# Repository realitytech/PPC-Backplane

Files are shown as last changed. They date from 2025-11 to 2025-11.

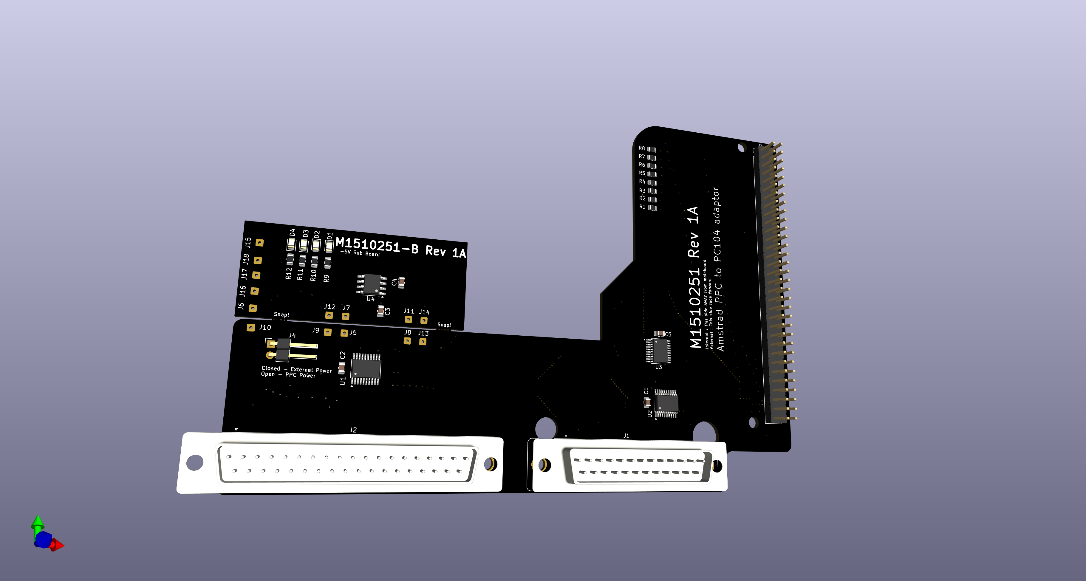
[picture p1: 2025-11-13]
M1510251 - PPC Conn.png

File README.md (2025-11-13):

# PPC-Backplane
Amstrad PPC640 and PPC512 Internal PC104 Backplane

M1510251 - PPC Conn

This adds an internal PC104 compatible slot to the PPC640 and PPC512 in the modem bay.
The board is designed to fit inside the machine soldering on the underside of the main board but can be fitted with through hole sockets and used externally too for testing and development.

This is the inital release version and corrects a few issues with the very first issue. The schematic and PCB need tidying.

NOTE: This version is UNTESTED and has not been built yet. It *should* work as it's an evolution of a design that DOES work. However it's missing changes that the test board has, notably.
Pullups on A8-A16, these seem to be not needed on all units.
Pullups on D0-D7 are optional, both units I have here already have these on the board.

The plan is to move to 74xxx16245 chips to keep to two chips but buffer ALL lines.

Licence/Useage:
Please credit the source. This is a non-commercial project and you may do with it as you wish for PERSONAL USE ONLY
Commercial use is strictly forbidden.

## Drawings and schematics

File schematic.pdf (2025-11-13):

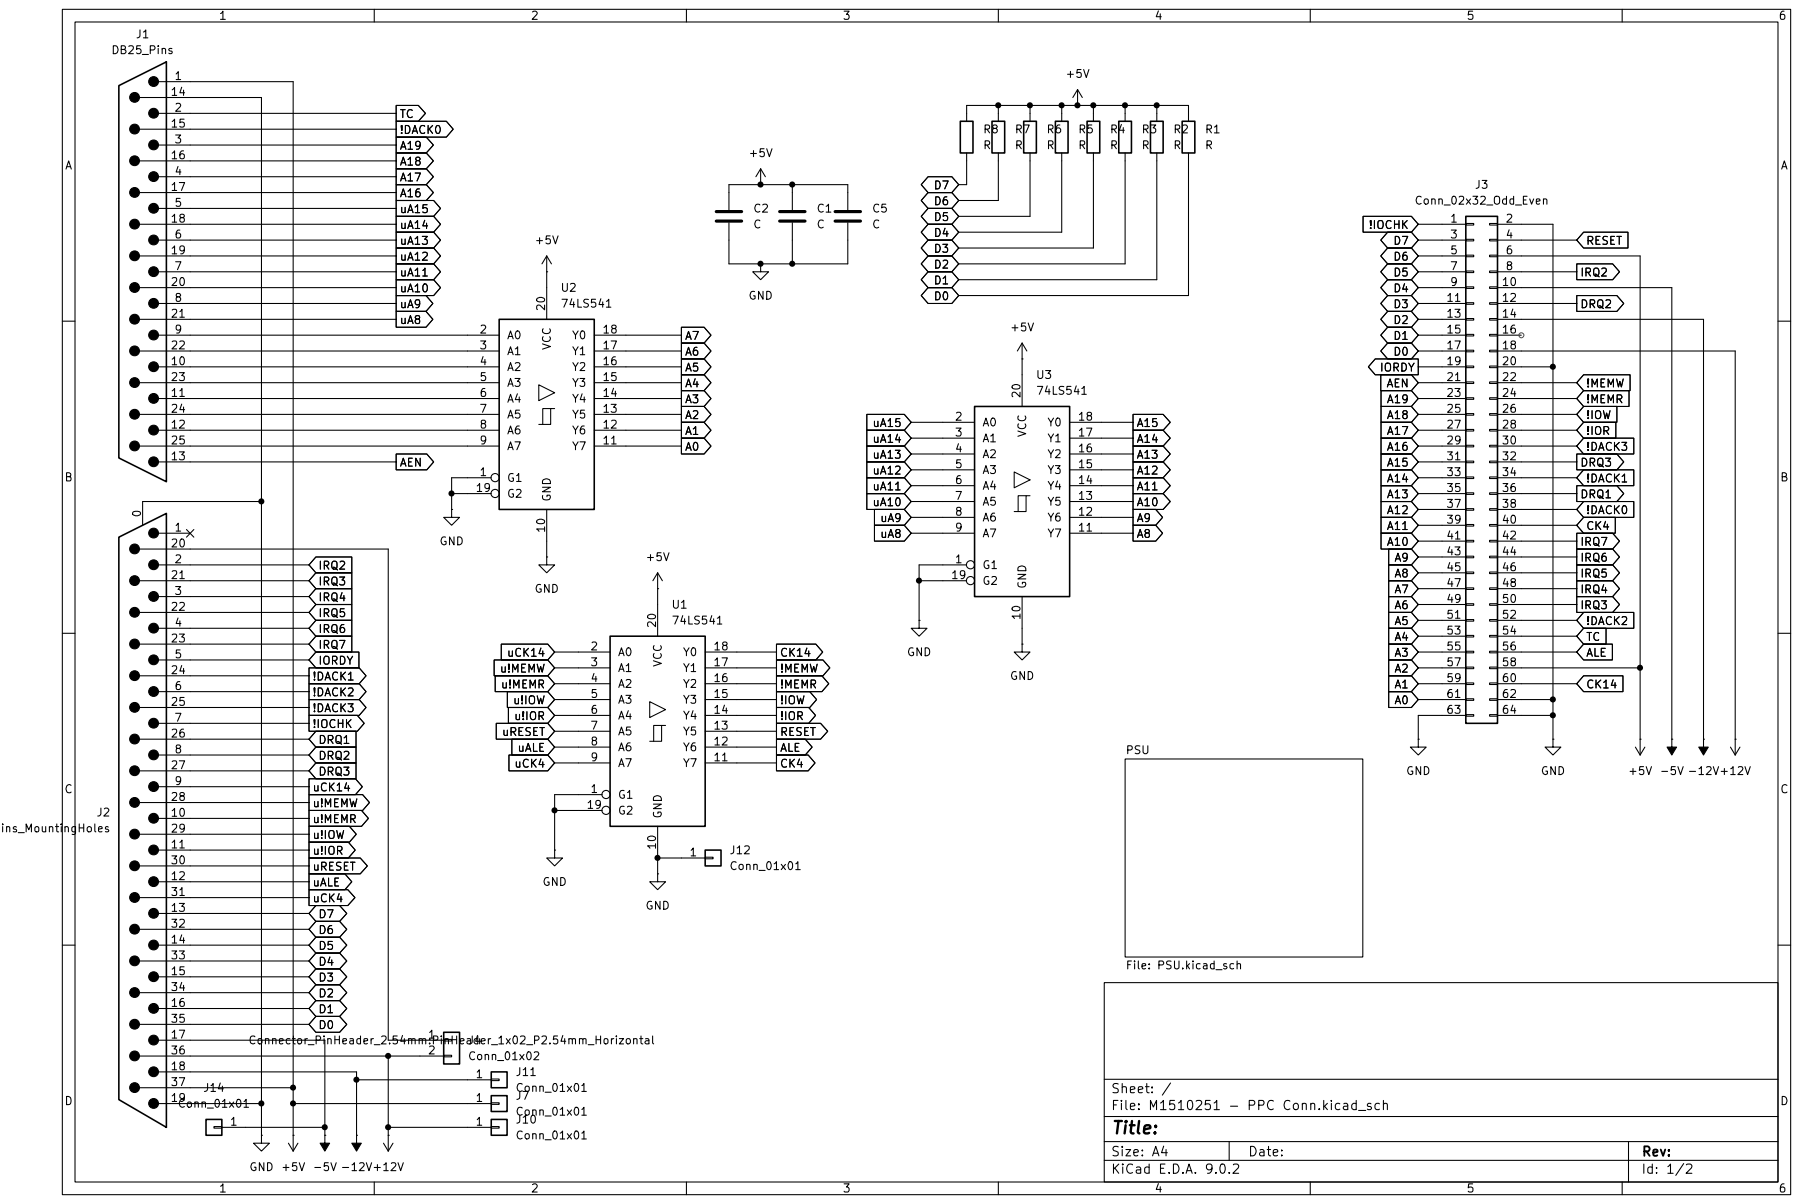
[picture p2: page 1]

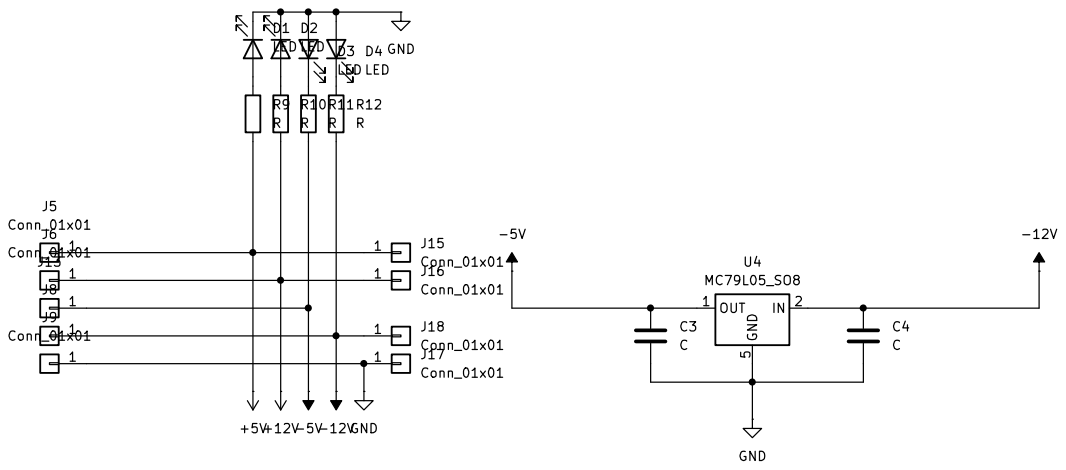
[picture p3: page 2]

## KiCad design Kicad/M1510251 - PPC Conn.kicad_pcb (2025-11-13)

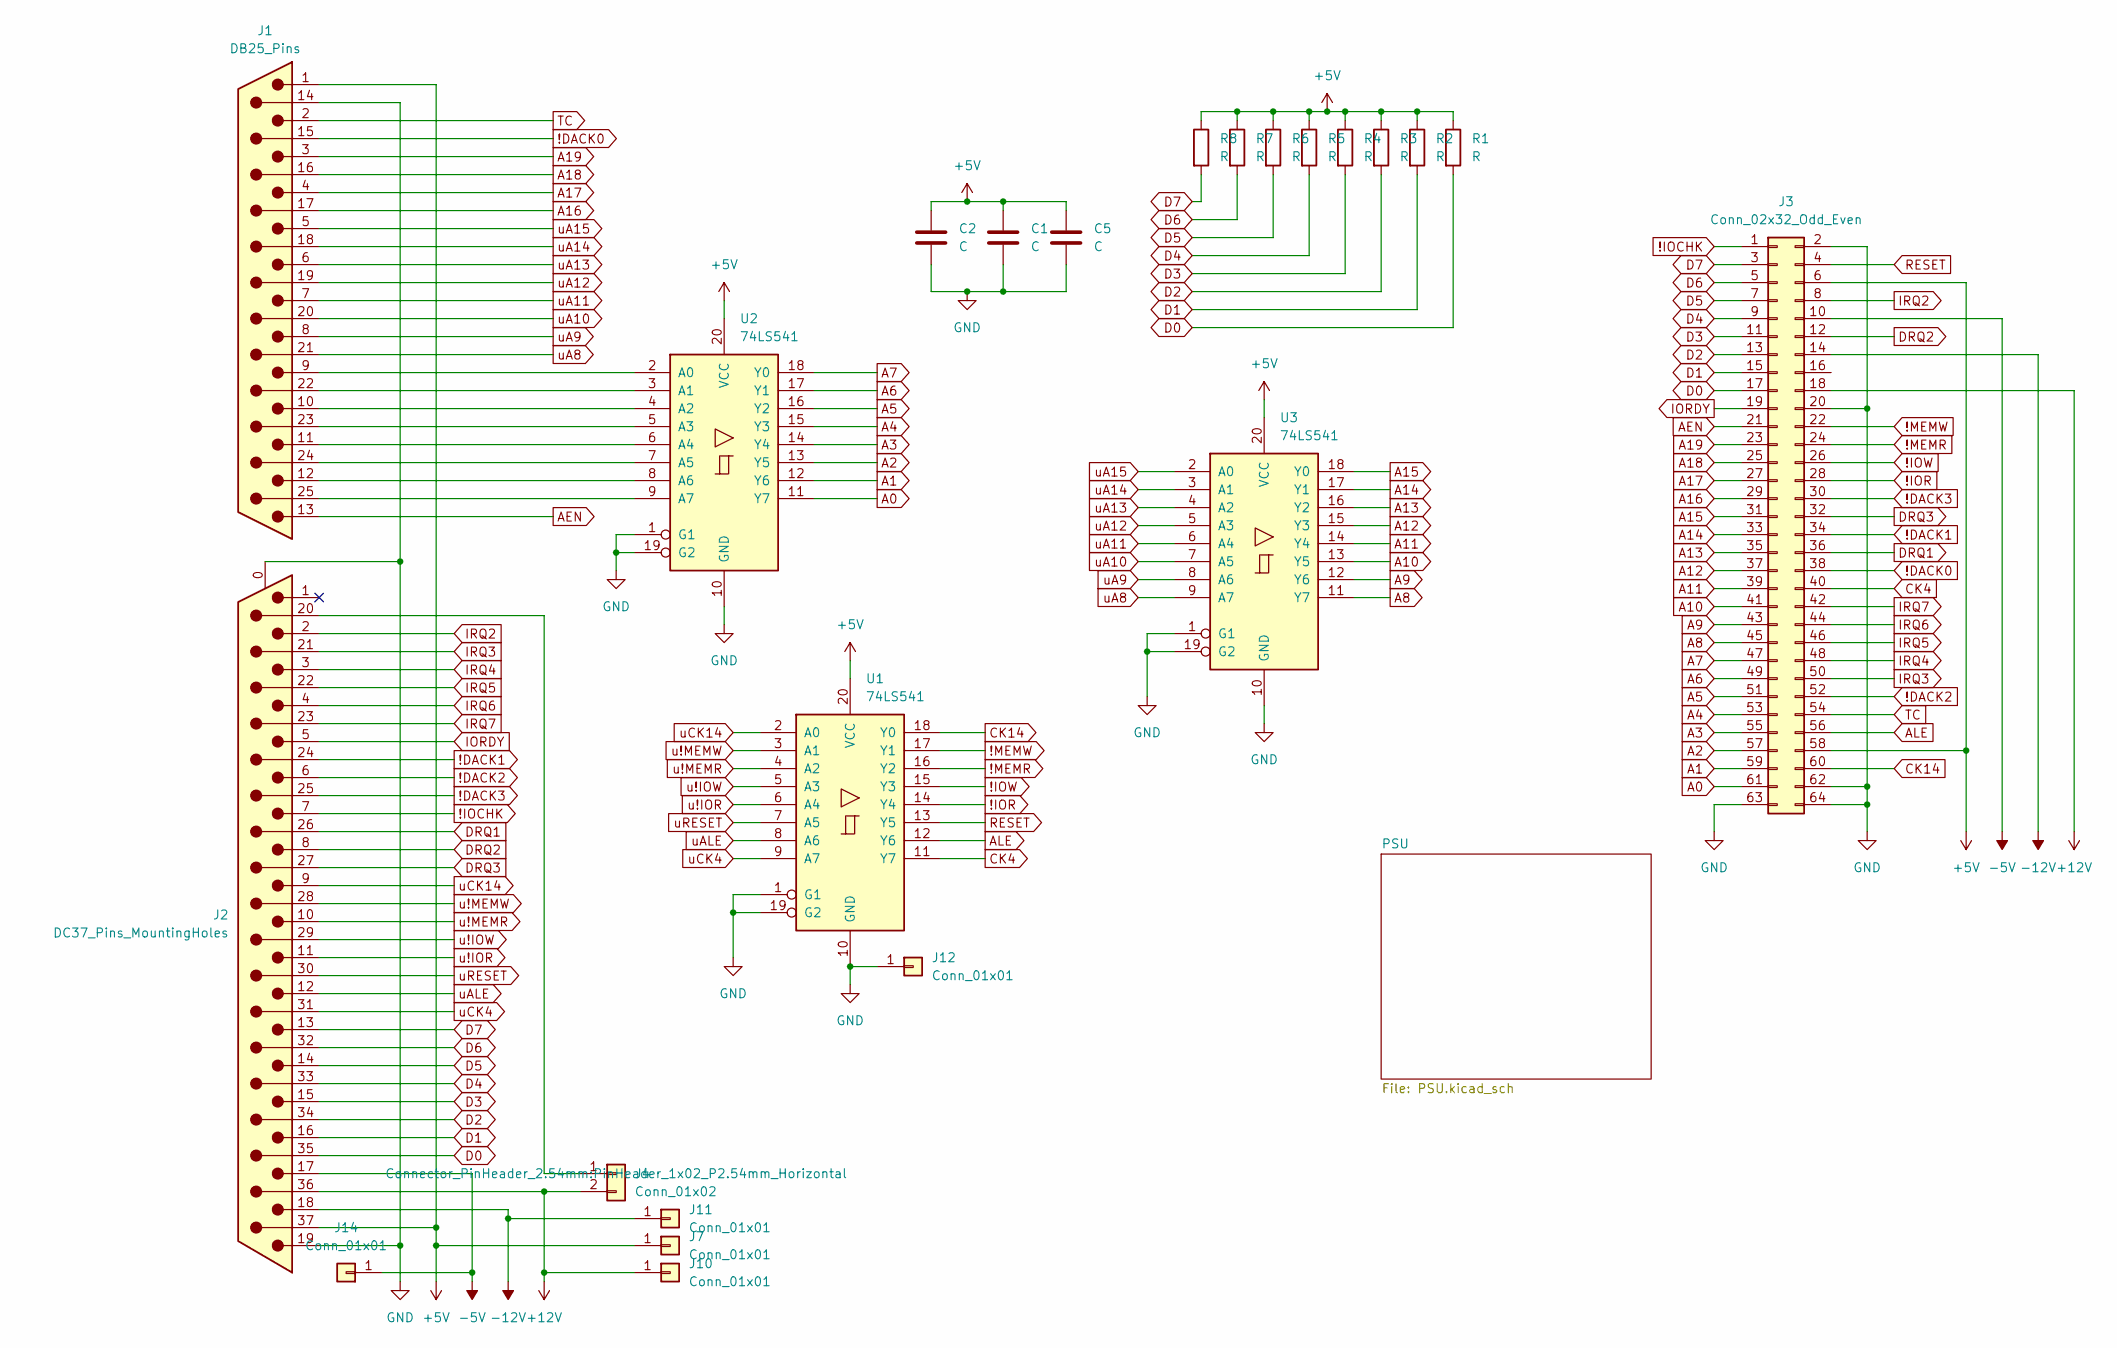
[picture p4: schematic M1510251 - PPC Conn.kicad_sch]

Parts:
C1, C2, C5: C; C_0805_2012Metric
J1: DB25_Pins; DSUB-25_Pins_Vertical_P2.77x2.84mm_MountingHoles
J2: DC37_Pins_MountingHoles; DSUB-37_Pins_Vertical_P2.77x2.84mm_MountingHoles
J3: Conn_02x32_Odd_Even; PinHeader_2x32_P2.54mm_Vertical
J4: Conn_01x02; PinHeader_1x02_P2.54mm_Horizontal
J7, J10, J11, J12, J14: Conn_01x01; SolderWire-0.15sqmm_1x01_D0.5mm_OD1.5mm
R1, R2, R3, R4, R5, R6, R7, R8: R; R_0805_2012Metric
U1, U2, U3: 74LS541; SSOP-20_4.4x6.5mm_P0.65mm

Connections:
!DACK0: J1.15, J3.38
!DACK1: J2.24, J3.34
!DACK2: J2.6, J3.52
!DACK3: J2.25, J3.30
!IOCHK: J2.7, J3.1
!IOR: J3.28, U1.14 (Y4)
!IOW: J3.26, U1.15 (Y3)
!MEMR: J3.24, U1.16 (Y2)
!MEMW: J3.22, U1.17 (Y1)
+5V: C1.1, C2.1, C5.1, J1.1, J2.37, J3.6, J3.58, J7.1, R1.1, R2.1, R3.1, R4.1, R5.1, R6.1, R7.1, R8.1, U1.20 (VCC), U2.20 (VCC), U3.20 (VCC); also elsewhere on the board
+12V: J2.36, J3.18, J4.2, J10.1; also elsewhere on the board
-5V: J2.17, J3.10, J14.1; also elsewhere on the board
-12V: J2.18, J3.14, J11.1; also elsewhere on the board
A0: J3.61, U2.11 (Y7)
A1: J3.59, U2.12 (Y6)
A2: J3.57, U2.13 (Y5)
A3: J3.55, U2.14 (Y4)
A4: J3.53, U2.15 (Y3)
A5: J3.51, U2.16 (Y2)
A6: J3.49, U2.17 (Y1)
A7: J3.47, U2.18 (Y0)
A8: J3.45, U3.11 (Y7)
A9: J3.43, U3.12 (Y6)
A10: J3.41, U3.13 (Y5)
A11: J3.39, U3.14 (Y4)
A12: J3.37, U3.15 (Y3)
A13: J3.35, U3.16 (Y2)
A14: J3.33, U3.17 (Y1)
A15: J3.31, U3.18 (Y0)
A16: J1.17, J3.29
A17: J1.4, J3.27
A18: J1.16, J3.25
A19: J1.3, J3.23
AEN: J1.13, J3.21
ALE: J3.56, U1.12 (Y6)
CK4: J3.40, U1.11 (Y7)
CK14: J3.60, U1.18 (Y0)
D0: J2.35, J3.17, R1.2
D1: J2.16, J3.15, R2.2
D2: J2.34, J3.13, R3.2
D3: J2.15, J3.11, R4.2
D4: J2.33, J3.9, R5.2
D5: J2.14, J3.7, R6.2
D6: J2.32, J3.5, R7.2
D7: J2.13, J3.3, R8.2
DRQ1: J2.26, J3.36
DRQ2: J2.8, J3.12
DRQ3: J2.27, J3.32
GND: C1.2, C2.2, C5.2, J1.14, J2.0 (PAD), J2.19, J3.2, J3.20, J3.62, J3.63, J3.64, J12.1, U1.1 (G1), U1.10 (GND), U1.19 (G2), U2.1 (G1), U2.10 (GND), U2.19 (G2), U3.1 (G1), U3.10 (GND), U3.19 (G2); also elsewhere on the board
IORDY: J2.5, J3.19
IRQ2: J2.2, J3.8
IRQ3: J2.21, J3.50
IRQ4: J2.3, J3.48
IRQ5: J2.22, J3.46
IRQ6: J2.4, J3.44
IRQ7: J2.23, J3.42
unnamed: J1.22, U2.3 (A1)
unnamed: J1.23, U2.5 (A3)
unnamed: J1.24, U2.7 (A5)
unnamed: J1.25, U2.9 (A7)
unnamed: J2.20, J4.1
unnamed: J1.9, U2.2 (A0)
unnamed: J1.10, U2.4 (A2)
unnamed: J1.11, U2.6 (A4)
unnamed: J1.12, U2.8 (A6)
RESET: J3.4, U1.13 (Y5)
TC: J1.2, J3.54
u!IOR: J2.11, U1.6 (A4)
u!IOW: J2.29, U1.5 (A3)
u!MEMR: J2.10, U1.4 (A2)
u!MEMW: J2.28, U1.3 (A1)
uA8: J1.21, U3.9 (A7)
uA9: J1.8, U3.8 (A6)
uA10: J1.20, U3.7 (A5)
uA11: J1.7, U3.6 (A4)
uA12: J1.19, U3.5 (A3)
uA13: J1.6, U3.4 (A2)
uA14: J1.18, U3.3 (A1)
uA15: J1.5, U3.2 (A0)
uALE: J2.12, U1.8 (A6)
uCK4: J2.31, U1.9 (A7)
uCK14: J2.9, U1.2 (A0)
uRESET: J2.30, U1.7 (A5)

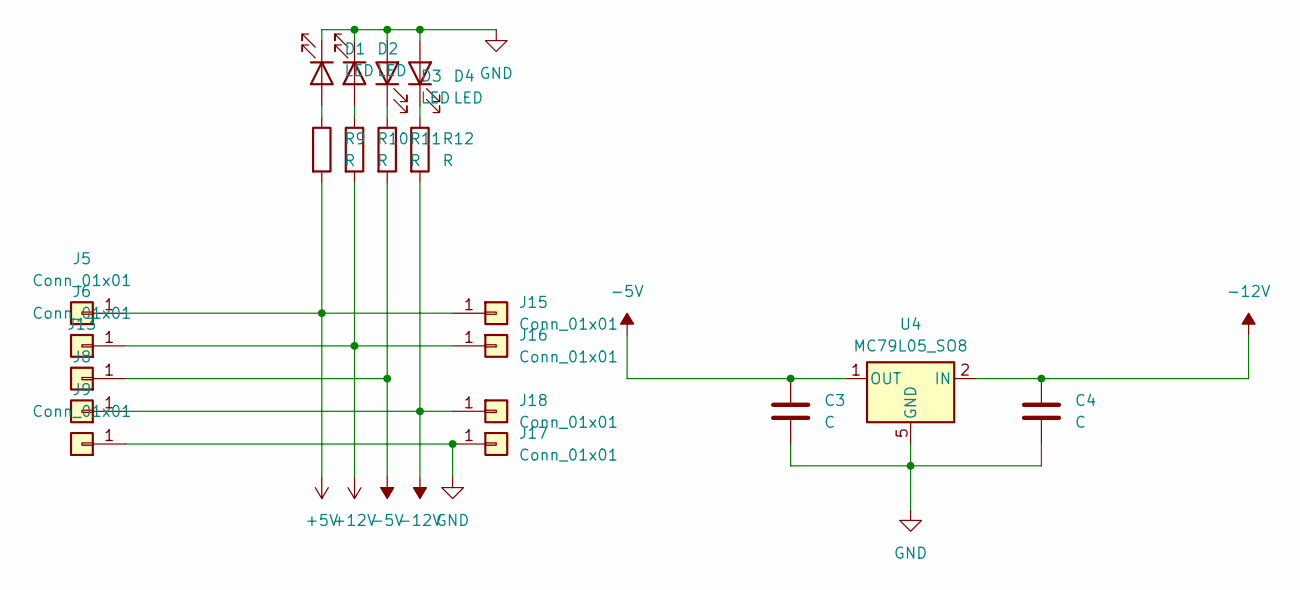
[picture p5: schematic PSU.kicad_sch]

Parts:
C3, C4: C; C_0805_2012Metric
D1, D2, D3, D4: LED; LED_0805_2012Metric
J5, J6, J8, J9, J13, J15, J16, J17, J18: Conn_01x01; SolderWire-0.15sqmm_1x01_D0.5mm_OD1.5mm
R9, R10, R11, R12: R; R_0805_2012Metric
U4: MC79L05_SO8; SOIC-8_3.9x4.9mm_P1.27mm

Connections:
+5V: J5.1, J15.1, R9.2; also elsewhere on the board
+12V: J6.1, J16.1, R10.2; also elsewhere on the board
-5V: C3.1, J13.1, R11.2, U4.1 (OUT); also elsewhere on the board
-12V: C4.1, J8.1, J18.1, R12.2, U4.2 (IN), U4.3 (IN), U4.6 (IN), U4.7 (IN); also elsewhere on the board
GND: C3.2, C4.2, D1.1 (K), D2.1 (K), D3.2 (A), D4.2 (A), J9.1, J17.1, U4.5 (GND); also elsewhere on the board
unnamed: D1.2 (A), R9.1
unnamed: D2.2 (A), R10.1
unnamed: D3.1 (K), R11.1
unnamed: D4.1 (K), R12.1

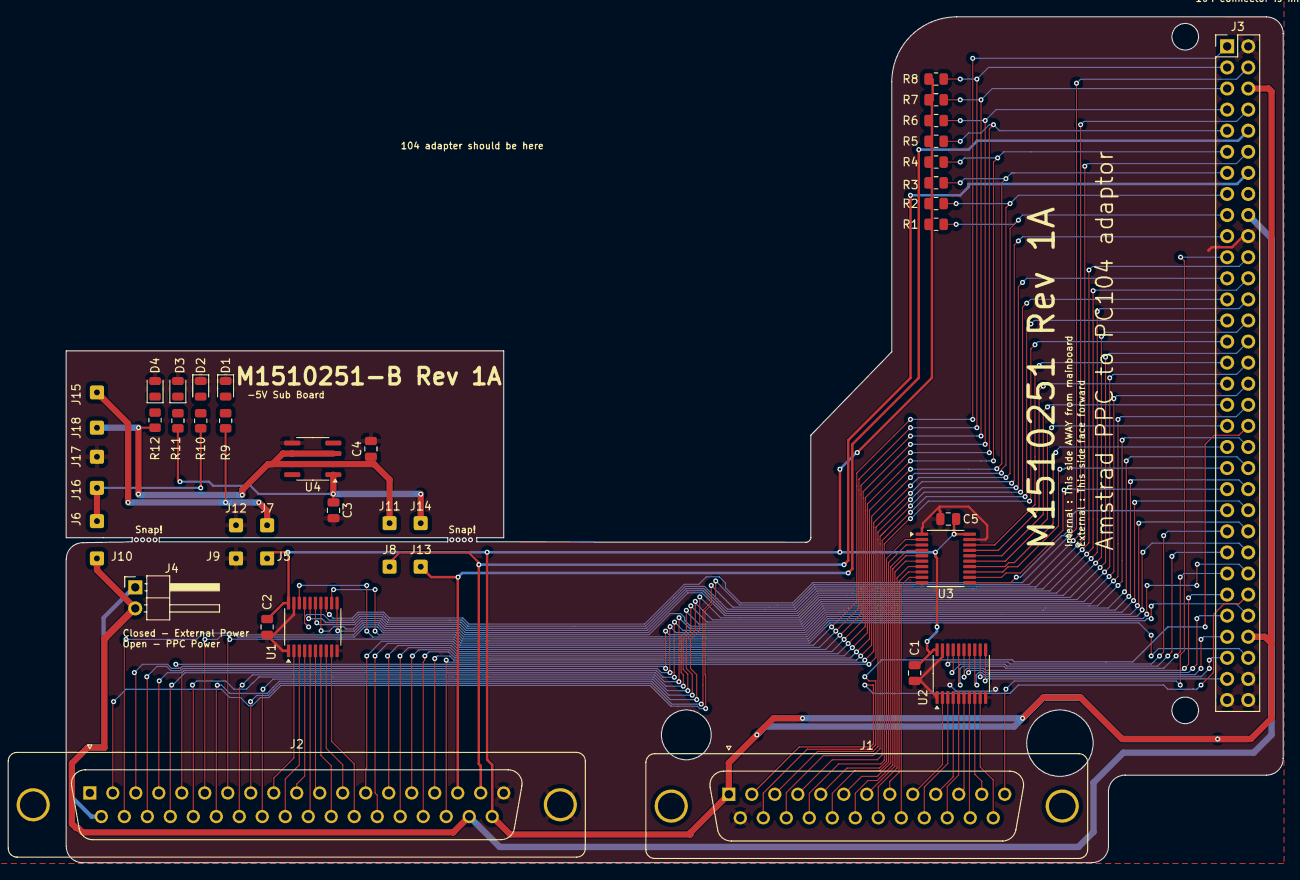
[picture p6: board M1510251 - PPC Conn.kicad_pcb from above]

Board: 2 copper layers, 146.6 x 101.9 mm, 43 parts (0 on the bottom side), 87 nets.
